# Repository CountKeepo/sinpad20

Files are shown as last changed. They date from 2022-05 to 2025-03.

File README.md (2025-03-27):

# SINPAD20



## This is my Saatanan Iso Nappi macroPAD with 20 keys, or SINPAD20 for short. 

It is a VIAL-firmware based macropad with a CCCP Missile button (KE-011) as a quirky huge enter button. 
The case is designed and made by [Migii](https://github.com/mkylama) and will most definitely not flip over when you press the huge red button.

**Fun facts:**
- The infamous AZ-5 scram button, which caused the disaster in Chernobyl, was a KE-011 button
- After the accident, starting from 1987, all RBMK reactors had their AZ-5 buttons replaced with a switch
  - The reason for this was that the push-button was prone to multiple inputs.
  - In Chernobyls case, the button press had actually registered twice.

## PCB components list:
- 1 x Atmega32u4 based Pro Micro
- 19 x Cherry MX spec switches of your choice + keycaps
- 1 x CCCP Missile button (KE-011 button, check Ebay etc.)
- 20 x Throughhole 1N4148 diodes or 0805 SMD diodes
- 2 x pieces of electrical wire for hooking up the big ass button to the PCB
- 1 x PCB-mounted 2U stabilizer

## Case - Designed by [Migii](https://github.com/mkylama)
You can find the case files in the [Case-files folder.](https://github.com/CountKeepo/sinpad20/tree/main/Case-files)

### Hardware needed for case build

- 3D-printed material of your choice

- 8 x M2 Heat inserts, 3 mm tall

- 8 x M2x5 countersunk screws, aka 5 mm tall

## Firmware
You can find a premade VIAL compatible firmware file in the [Firmware folder.](https://github.com/CountKeepo/sinpad20/tree/main/Firmware)

## Ordering PCB's
You can find premade gerbers in the [Gerbers folder.](https://github.com/CountKeepo/SIN-pad/tree/main/Sinpad%20Gerbers)  

Otherwise you can use the KiCad files to make your own gerbers.

I ordered my PCB's from ALLPCB and they turned out okay. I cannot guarantee other that other manufacturers will do a good job. 

## Pictures of project:



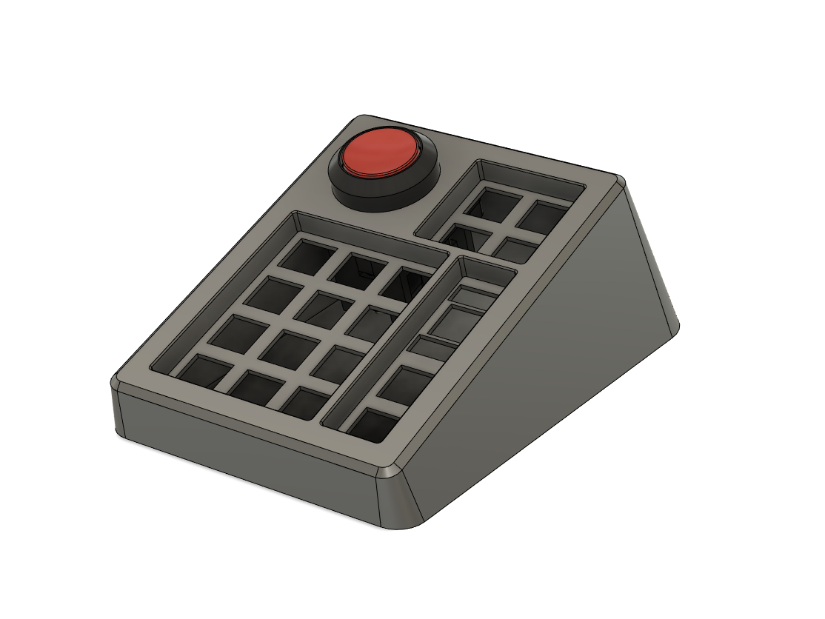
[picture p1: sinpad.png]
Sinpad picture


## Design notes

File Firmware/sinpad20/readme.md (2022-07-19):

# sinpad20

sinpad20

*A short description of the keyboard/project*

* Keyboard Maintainer: [Count Keepo](https://github.com/CountKeepo)
* Hardware Supported: *The PCBs, controllers supported*
* Hardware Availability: *Links to where you can find this hardware*

Make example for this keyboard (after setting up your build environment):

    make sinpad20:default

Flashing example for this keyboard:

    make sinpad20:default:flash

See the [build environment setup](https://docs.qmk.fm/#/getting_started_build_tools) and the [make instructions](https://docs.qmk.fm/#/getting_started_make_guide) for more information. Brand new to QMK? Start with our [Complete Newbs Guide](https://docs.qmk.fm/#/newbs).

## Bootloader

Enter the bootloader in 3 ways:

* **Bootmagic reset**: Hold down the key at (0,0) in the matrix (usually the top left key or Escape) and plug in the keyboard
* **Physical reset button**: Briefly press the button on the back of the PCB - some may have pads you must short instead
* **Keycode in layout**: Press the key mapped to `RESET` if it is available

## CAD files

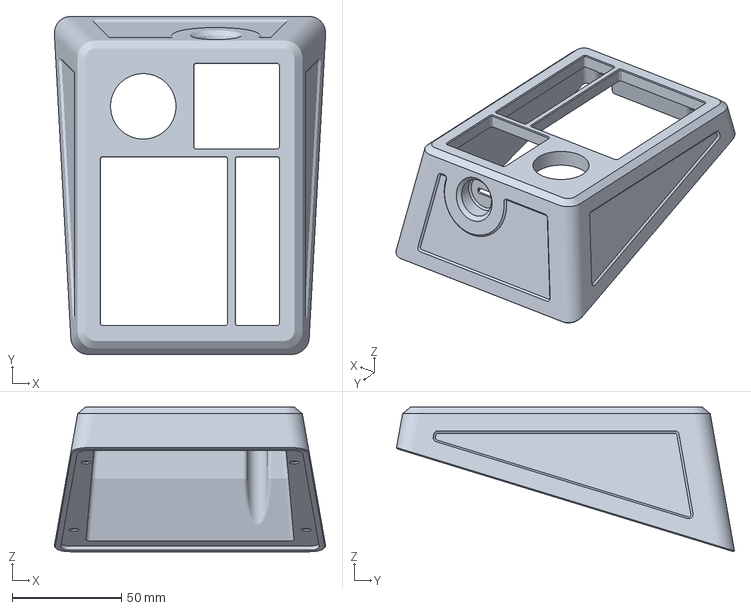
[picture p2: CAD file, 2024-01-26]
Case-files/sinpad_case.3mf
124.4 x 155.0 x 66.3 mm

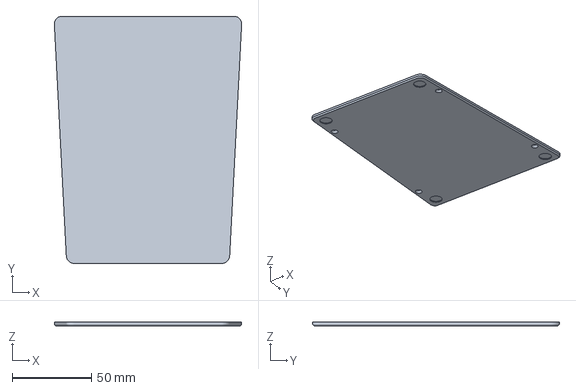
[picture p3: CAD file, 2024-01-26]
Case-files/sinpad_bottom.3mf
118.2 x 155.9 x 2.50 mm

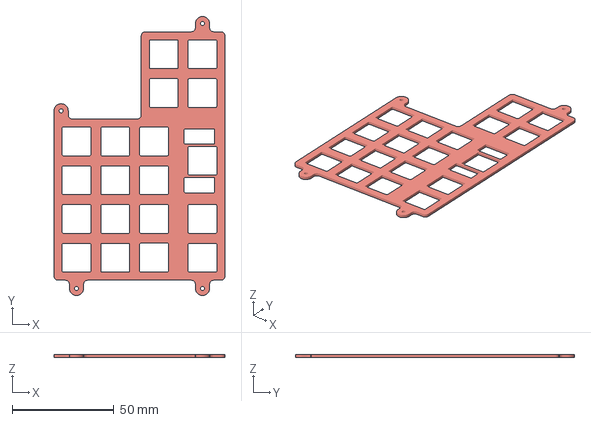
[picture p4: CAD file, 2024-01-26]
Case-files/sinpad_plate.3mf
84.0 x 137.1 x 1.50 mm

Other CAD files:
Case-files/SinPad.f3z

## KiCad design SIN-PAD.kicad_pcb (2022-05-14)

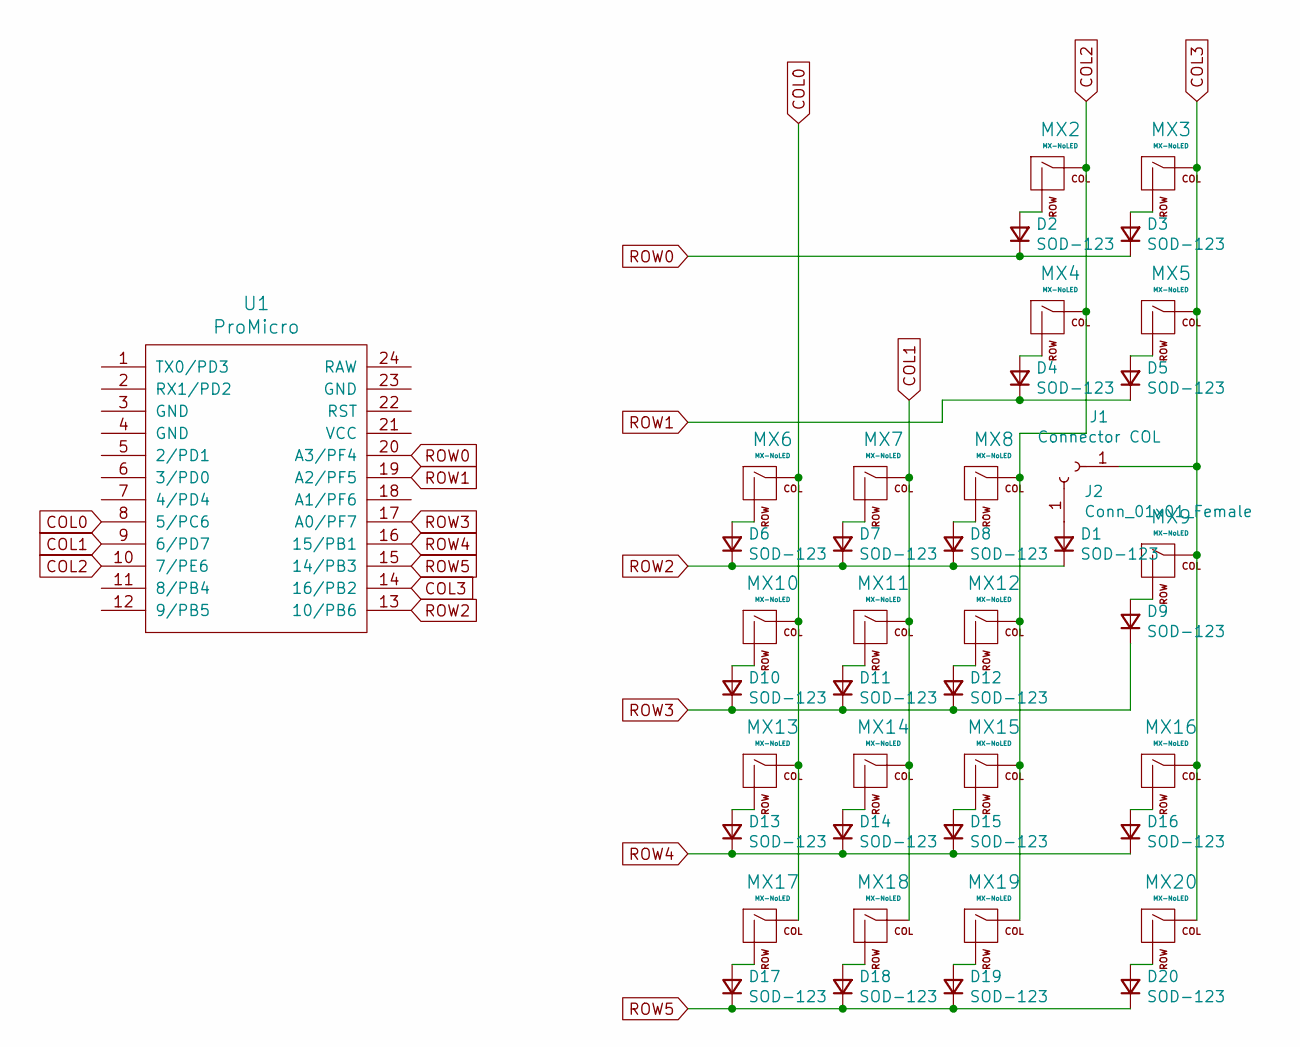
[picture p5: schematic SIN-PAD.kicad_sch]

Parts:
D1, D2, D3, D4, D5, D6, D7, D8, D9, D10, D11, D12, D13, D14, D15, D16, D17, D18, D19, D20: SOD-123; Diode-Hybrid-Back
J1: Connector COL; SolderWire-0.5sqmm_1x01_D0.9mm_OD2.3mm
J2: Conn_01x01_Female; SolderWire-0.5sqmm_1x01_D0.9mm_OD2.3mm
MX2, MX3, MX4, MX5, MX6, MX7, MX8, MX10, MX11, MX12, MX13, MX14, MX15, MX16, MX17, MX18, MX19, MX20: MX-NoLED; MXOnly-1U-NoLED
MX9: MX-NoLED; MXOnly-2U-NoLED
U1: ProMicro; ArduinoProMicro

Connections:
COL0: MX6.1 (COL), MX10.1 (COL), MX13.1 (COL), MX17.1 (COL), U1.8 (5/PC6)
COL1: MX7.1 (COL), MX11.1 (COL), MX14.1 (COL), MX18.1 (COL), U1.9 (6/PD7)
COL2: MX2.1 (COL), MX4.1 (COL), MX8.1 (COL), MX12.1 (COL), MX15.1 (COL), MX19.1 (COL), U1.10 (7/PE6)
COL3: J1.1, MX3.1 (COL), MX5.1 (COL), MX9.1 (COL), MX16.1 (COL), MX20.1 (COL), U1.14 (16/PB2)
unnamed: D1.2 (A), J2.1
unnamed: D2.2 (A), MX2.2 (ROW)
unnamed: D3.2 (A), MX3.2 (ROW)
unnamed: D4.2 (A), MX4.2 (ROW)
unnamed: D5.2 (A), MX5.2 (ROW)
unnamed: D6.2 (A), MX6.2 (ROW)
unnamed: D7.2 (A), MX7.2 (ROW)
unnamed: D8.2 (A), MX8.2 (ROW)
unnamed: D9.2 (A), MX9.2 (ROW)
unnamed: D10.2 (A), MX10.2 (ROW)
unnamed: D11.2 (A), MX11.2 (ROW)
unnamed: D12.2 (A), MX12.2 (ROW)
unnamed: D13.2 (A), MX13.2 (ROW)
unnamed: D14.2 (A), MX14.2 (ROW)
unnamed: D15.2 (A), MX15.2 (ROW)
unnamed: D16.2 (A), MX16.2 (ROW)
unnamed: D17.2 (A), MX17.2 (ROW)
unnamed: D18.2 (A), MX18.2 (ROW)
unnamed: D19.2 (A), MX19.2 (ROW)
unnamed: D20.2 (A), MX20.2 (ROW)
ROW0: D2.1 (K), D3.1 (K), U1.20 (A3/PF4)
ROW1: D4.1 (K), D5.1 (K), U1.19 (A2/PF5)
ROW2: D1.1 (K), D6.1 (K), D7.1 (K), D8.1 (K), U1.13 (10/PB6)
ROW3: D9.1 (K), D10.1 (K), D11.1 (K), D12.1 (K), U1.17 (A0/PF7)
ROW4: D13.1 (K), D14.1 (K), D15.1 (K), D16.1 (K), U1.16 (15/PB1)
ROW5: D17.1 (K), D18.1 (K), D19.1 (K), D20.1 (K), U1.15 (14/PB3)

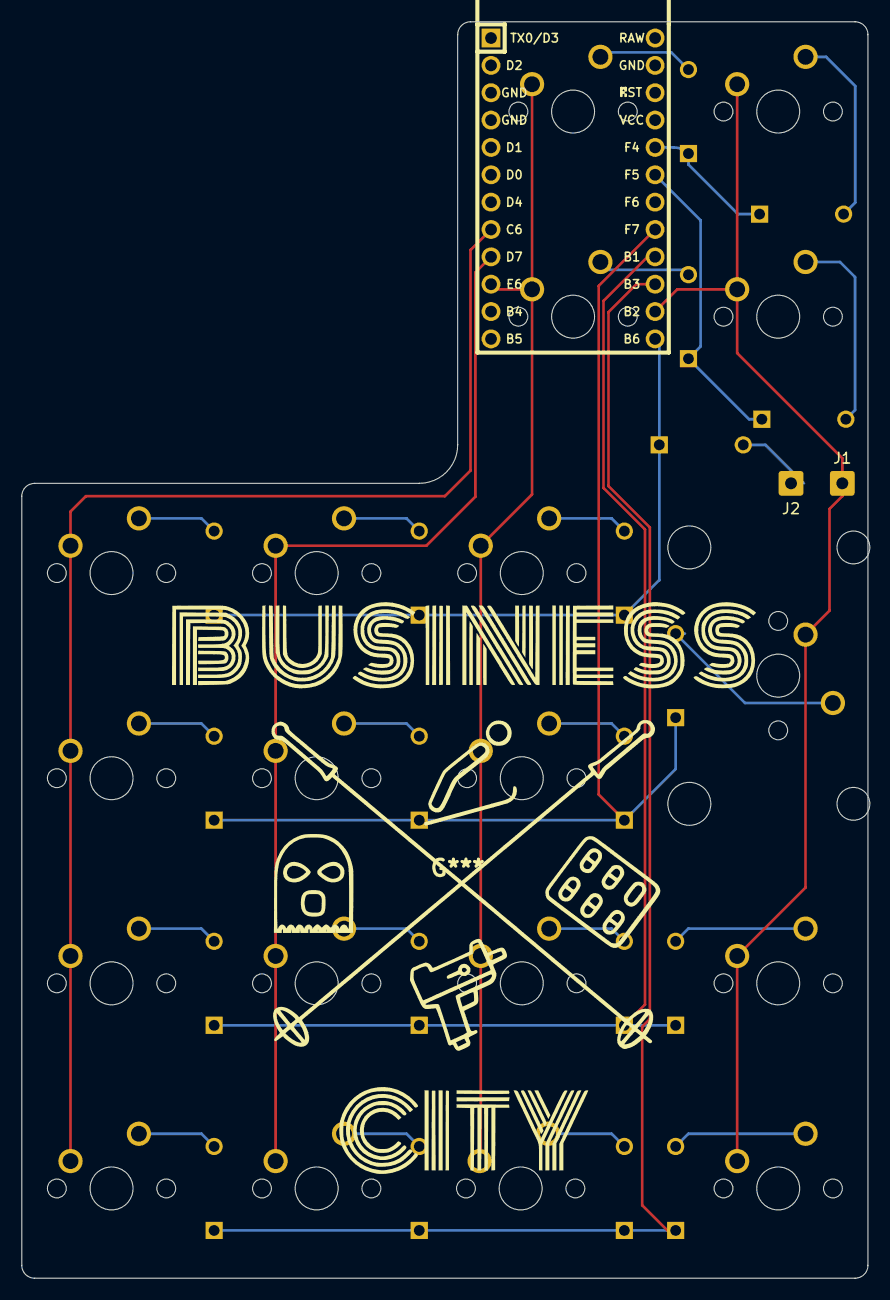
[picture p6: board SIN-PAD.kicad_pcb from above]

Board: 2 copper layers, 78.6 x 116.7 mm, 43 parts (1 on the bottom side), 30 nets.

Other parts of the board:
  : LOGO; pikkunimmari

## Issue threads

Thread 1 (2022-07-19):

Case is missing

CountKeepo, 2022-07-19:
oh dear

Closed 2022-09-28.

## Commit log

2021-10-04 Pelkät projufilut
    [SIN-PAD.kicad_pcb, SIN-PAD.sch]
2021-10-04 Uusia edustuksia
    [SIN-PAD.sch]
2021-10-04 Big brain commit 23:36
    [SIN-PAD.sch]
2022-05-14 Muutamii muutoksia
    [SIN-PAD-B_Cu.gbl, SIN-PAD-B_Mask.gbs, SIN-PAD-B_Paste.gbp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]
2024-01-26 Added case files finally
    Blame it on procrastination or forgetting to ask for it but I finally remembered to add the case files.
    [SinPad.f3z, sinpad_bottom.3mf, sinpad_case.3mf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]
